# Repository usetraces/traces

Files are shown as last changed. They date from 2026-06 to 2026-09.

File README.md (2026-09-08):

# traces — supercharged ee tools

Open-source tooling for KiCad: semantic component sourcing and schematic review
that runs entirely on **your** machine against **your** API keys. No accounts, no
hosted backend, no billing.

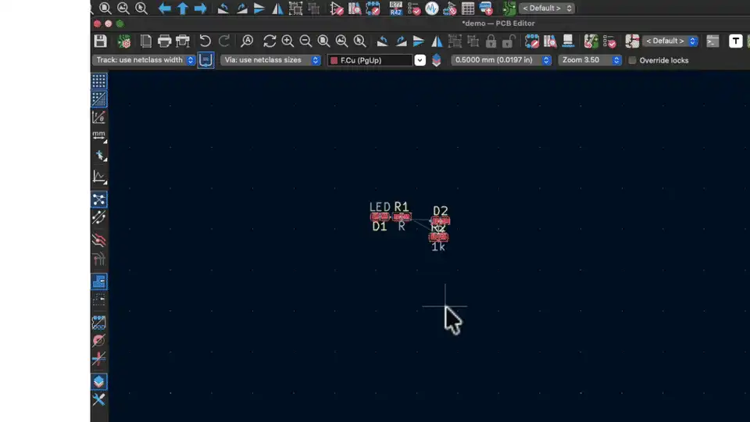
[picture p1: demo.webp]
traces sourcing parts inside KiCad


There are three tools:

1. **mcp** — a local sourcing server you install into your agent
2. **kicad extension** — a KiCad plugin that talks to the local server
3. **semantic rule check (SRC)** — a `/src` skill for Claude Code / Codex

## Setup

One command installs all three tools (server, KiCad plugin, `/src` skill):

```bash
git clone https://github.com/usetraces/traces.git
cd traces
./install.sh           # creates .env, installs deps; pulls a local model if no cloud key
```

`./install.sh` creates `.env` for you. Add keys to it as needed, then re-run if
you like — sourcing works against the local model with **no keys at all**. You
can also install just one piece: `./install.sh mcp | kicad | skill`.

All three tools read keys from the repo-root `.env`:

| Key | Needed for |
|---|---|
| `OPENROUTER_API_KEY` | cloud LLM for sourcing (optional — blank = fully local) |
| `MOUSER_API_KEY` | Mouser sourcing |
| `DIGIKEY_CLIENT_ID` / `DIGIKEY_CLIENT_SECRET` | Digi-Key sourcing |
| _(none)_ | JLCPCB / LCSC sourcing works with no key |

Prerequisites: `./install.sh` auto-installs [uv](https://docs.astral.sh/uv/) and
(for local mode) Ollama. You need Node.js 20+ and KiCad already present.

---

## 1. mcp

A local server that turns natural language ("low-Rds N-MOSFET in SOT-23",
"100nF 0402 X7R") into ranked, in-stock parts across JLCPCB/LCSC, Digi-Key, and
Mouser. The OpenRouter-backed Node agents interpret each request like an
engineer, query the supplier APIs, and the results are merged and ranked
in-stock-first, then by footprint match and price.

```bash
cd mcp
./install.sh        # uv sync + npm install
```

**Run it as a local HTTP server** (what the KiCad extension connects to):

```bash
uv run traces-serve   # serves http://127.0.0.1:8000
```

**Or install the stdio MCP into your agent.** For Claude Code:

```bash
claude mcp add traces -- uv run --directory /path/to/traces/mcp traces-mcp
```

Tools exposed to the agent:

- `source_component(query, footprint?, suppliers?, max_price?, min_qty?, count?)` — ranked in-stock candidates
- `find_datasheet(lcsc)` — datasheet PDF URL for an LCSC C-number
- `netlist_check(xml, check)` — run a semantic rule check over netlist XML

Override the model with `DEFAULT_MODEL` in `.env` (default
`google/gemini-3.1-flash-lite`).

### Running fully local (no OpenRouter key)

If `OPENROUTER_API_KEY` is blank — **or set but broken/unreachable** — traces
automatically falls back to a local [Ollama](https://ollama.com) model. No key,
nothing leaves your machine. The model is `OLLAMA_MODEL` (default `gemma4`).

`./install.sh` sets this up for you: when there's no OpenRouter key it installs
Ollama and pulls `OLLAMA_MODEL`. To do it by hand, or to use a different
tool-capable model (sourcing uses function-calling):

```bash
ollama pull gemma4        # verified; qwen2.5 / llama3.1 also work
# leave OPENROUTER_API_KEY blank in .env (OLLAMA_MODEL=gemma4 is the default)
uv run traces-serve
```

The SRC checks (JSON only) work with any chat model; sourcing needs tool
support. Local runs are slower (tens of seconds per sourcing call) but produce
the same ranked, in-stock results.

### Eval

Smoke-test the pipeline against whichever provider is active:

```bash
uv run traces-eval            # sourcing (all suppliers) + SRC checks
uv run traces-eval --src-only # netlist checks only (no tool-calling needed)
```

Verified end-to-end against local `gemma4` via Ollama — both the SRC checks and
JLCPCB/Digi-Key/Mouser sourcing pass with no OpenRouter key.

### Benchmark

Rank the local model against a set of OpenRouter models on accuracy, speed, and
price. Each model runs the JLCPCB sourcing agent (no supplier key needed) over a
small fixed case set, several trials each:

```bash
uv run traces-bench               # local gemma4 + 5 OpenRouter models, 3 trials
uv run traces-bench --trials 1    # quick pass
uv run traces-bench --no-local    # OpenRouter models only
```

Latest run — 6 models × 3 cases × 3 trials = 54 sourcing calls (JLCPCB):

| Model | Accuracy | Median speed | Avg $/run | Fails |
|---|---|---|---|---|
| `google/gemini-3.1-flash-lite` (shipped default) | 100% | 5.6s | $0.00059 | 0/9 |
| `anthropic/claude-haiku-4.5` | 100% | 7.4s | $0.00394 | 0/9 |
| `qwen/qwen3-235b-a22b-2507` | 100% | 8.0s | $0.00018 | 0/9 |
| `openai/gpt-5-mini` | 100% | 20.9s | $0.00240 | 0/9 |
| `ollama/gemma4` (local) | 100% | 44.7s | $0.00000 | 0/9 |
| `google/gemini-3.5-flash` | 44% | 18.8s | $0.00796 | 0/9 |

Takeaways: the shipped default (`gemini-3.1-flash-lite`) is both the fastest and
the most accurate cloud option; `qwen3-235b` is nearly as good for ~3× less; the
local `gemma4` matches on accuracy at $0 but is ~8× slower. Accuracy here is a
keyword + footprint match proxy, not a guarantee of the optimal part — edit the
model list, cases, and trial count at the top of `mcp/src/traces_mcp/bench.py`.

---

## 2. kicad extension

For the KiCad Plugin and Content Manager package, see the
[installation guide](kicad-extension/README.md). Release maintainers can follow
the [PCM submission guide](kicad-extension/SUBMISSION.md).

A KiCad 10 PCB-editor plugin that reconciles schematic metadata, sources parts
into schematic properties, fetches datasheets, pulls KiCad symbols/footprints
from LCSC, and runs SRC — all against the local server above.

```bash
cd kicad-extension
./install.sh        # copies the plugin into your KiCad plugins dir
```

Then:

1. Start the server: `(cd ../mcp && uv run traces-serve)`
2. Restart KiCad so it loads the plugin.
3. Open a saved PCB → **Tools → External Plugins → traces**.

The plugin points at `http://127.0.0.1:8000`; it does not require sign-in.

---

## 3. semantic rule check (SRC)

A skill for Claude Code / Codex that reviews a local KiCad project for
**semantic** net problems ERC can't catch — net-label typos, inconsistent bus
naming, orphan (single-pin) nets, and near-duplicate net names. The agent does
the reasoning directly, so no server or key is needed.

Install the skill (Claude Code example):

```bash
mkdir -p ~/.claude/skills/src
cp src/SKILL.md ~/.claude/skills/src/
```

Then, from a directory containing a KiCad project:

```
/src
```

See [`src/SKILL.md`](src/SKILL.md) for what each check flags.

---

## Architecture

```
traces/
├── mcp/              # local sourcing server (FastMCP + FastAPI + Node agents)
│   └── src/traces_mcp/
│       ├── mcp_server.py   # stdio MCP  (traces-mcp)
│       ├── app.py          # local HTTP (traces-serve) for the KiCad extension
│       ├── semantic.py     # cross-supplier ranking
│       ├── suppliers/      # JLCPCB / Digi-Key / Mouser clients + sourcing
│       ├── netlist.py      # SRC checks (OpenRouter or local Ollama)
│       ├── library.py      # LCSC symbol/footprint via easyeda2kicad
│       └── agents/*.mjs    # sourcing agents (Node, OpenAI-compatible)
├── kicad-extension/  # KiCad plugin (traces.py)
└── src/              # the /src SRC skill (SKILL.md)
```

The KiCad extension speaks the same `/jobs/*` submit-and-poll contract the old
hosted backend used, so the local server is a drop-in: requests are computed
inline with an in-memory job store — no Redis, no auth, no billing.

## What changed from the hosted version

This repo is the open-source extraction of the original hosted product. Removed:
Supabase auth, Stripe billing, the marketing site / dashboard / stats pages, the
Redis + ARQ job queue, and all account/sign-in flows. The sourcing engine, the
KiCad plugin, and the SRC checks are preserved and rewired to run locally.

## License

MIT — see [LICENSE](LICENSE).

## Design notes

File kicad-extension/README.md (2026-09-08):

# traces for KiCad

Component sourcing, schematic properties, datasheets, library imports, and
semantic netlist checks, launched from the KiCad PCB Editor.

The first Plugin and Content Manager (PCM) package targets **KiCad 10 on macOS**
and is a testing release. The local server is installed separately.

## Install the local server

Install Node.js 20+ and Git, then run:

```sh
git clone https://github.com/usetraces/traces.git
cd traces
git checkout kicad-v2.0.0
./install.sh mcp
```

The installer sets up uv and Python dependencies (Python 3.11+). Configure the
clone's `.env` with your API keys. With no OpenRouter key, the installer attempts
to install Ollama and download the default model. Model downloads can be large.
See the repository README for provider settings and manual Ollama setup.

Run the server in a terminal and leave it running:

```sh
cd mcp
uv run traces-serve
```

The plugin connects to `http://127.0.0.1:8000`. PCM installs only the plugin;
it does not run the backend installer. Automatic server discovery is a convenience
for existing checkouts, not required when the server is already running.

## Install the plugin

1. Download `traces-kicad-2.0.0.zip` from the GitHub release.
2. In KiCad's project manager, open **Plugin and Content Manager**, select
   **Install from File**, choose the ZIP, and apply pending changes if prompted.
3. Restart the PCB Editor. Open a saved PCB belonging to your project.
4. Choose **Tools → External Plugins → traces** (or its toolbar button).

Once accepted into the official repository, traces will also be installable by
name in PCM. Until then, use the release ZIP.

If you previously ran `./install.sh kicad`, move the old `traces.py` and
`traces.png` out of `~/Documents/KiCad/10.0/scripting/plugins/` before restarting
KiCad to avoid duplicate plugin registrations. Keep a backup outside that folder.
Do not run the manual plugin installer on top of a PCM installation.

## Use and updates

The plugin edits schematic files on disk. Save and close the schematic editor
before applying edits, then reopen it to load the changes. Start with a copy of
your project. A running server is required for sourcing and semantic checks.

Local Ollama inference keeps model processing local; component sourcing and
library downloads still contact external suppliers. OpenRouter mode sends model
requests, including the netlist when running semantic checks, to that service.
Digi-Key and Mouser features may require your own supplier credentials.

Install subsequent plugin releases through PCM. Update the separate server to
the corresponding release as described in its release notes. Report problems at
https://github.com/usetraces/traces/issues with your KiCad version and OS, without
including API keys or private design files.

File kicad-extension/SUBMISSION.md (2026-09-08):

# KiCad PCM release and submission

Package: `com.github.usetraces.traces`

First release: `2.0.0` / Git tag `kicad-v2.0.0`

Target: KiCad 10.0, macOS, SWIG runtime, testing status

## Build

From the repository root:

```sh
python3 scripts/build_pcm.py
```

This creates:

- `dist/pcm/traces-kicad-2.0.0.zip` — plugin archive with a package entry point,
  source, icon, MIT license, setup guide, and archive metadata.
- `dist/pcm/submission/packages/com.github.usetraces.traces/metadata.json` —
  GitLab metadata with the final ZIP hash, URL, compressed size, and extracted size.

The ZIP is built from an explicit file list; it excludes `.env`, design files,
Python caches, and the server's dependencies. Builds with the same inputs and
Python/zlib toolchain produce identical bytes. Only the GitLab metadata has
`download_*` fields. `INSTALLED_VERSION` remains `0.0.0` so the old PyPI updater
does not run in PCM installations.

Optional schema validation:

```sh
curl -fL https://go.kicad.org/pcm/schemas/v2 -o /tmp/traces-pcm-v2.schema.json
uv run --no-project --with jsonschema python scripts/build_pcm.py \
  --schema /tmp/traces-pcm-v2.schema.json
```

## Verify and publish

1. Install the ZIP using PCM's **Install from File** and confirm the installed
   version. Avoid loading a duplicate manually installed copy.
2. Follow `README.md` in this directory to start the server and open the plugin
   from a saved PCB. Use a disposable project copy for write operations.
3. Commit the packaging files and documentation. Create the release tag on that
   commit; the source at the tag must match the ZIP's source.
4. Upload the ZIP to a public GitHub release named `traces for KiCad 2.0.0`, with
   tag `kicad-v2.0.0`. Mark the release as a prerelease while PCM status is testing.
5. Download the public release asset and check its SHA-256 against the generated
   submission metadata. Do not change the archive after this check.

## Submit to GitLab

1. Sign in with `glab auth login --hostname gitlab.com`.
2. Fork `https://gitlab.com/kicad/addons/metadata` and create a branch such as
   `add-traces` from its current `main`.
3. Copy the generated `packages/com.github.usetraces.traces/metadata.json` into
   the fork. Commit and push that branch.
4. Check the fork's validation pipeline. Its build job produces a temporary PCM
   repository URL; add that repository in KiCad and test installation.
5. Open a merge request targeting `kicad/addons/metadata:main` with the package
   purpose, release link, backend requirement, and exact validation performed.
   Do not claim supplier-policy approval or tests that have not happened.

Updates use additional merge requests adding release entries to the upstream
metadata. Keep prior entries in the upstream file; the builder emits only the
current version and must not replace upstream release history on later updates.

Official instructions: https://dev-docs.kicad.org/en/addons/

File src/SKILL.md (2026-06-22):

---
name: src
description: Semantic Rule Check (SRC) for KiCad projects — reviews a local KiCad schematic/netlist for net-label typos, naming inconsistencies, orphan (single-pin) nets, and near-duplicate net names. Use when the user runs /src or asks to semantically review a KiCad schematic in the working directory.
---

# SRC — Semantic Rule Check for KiCad

SRC reviews the KiCad project in the current working directory for **semantic**
net problems that KiCad's own ERC cannot catch — the kind of mistakes that pass
electrical rules but are still bugs (a misspelled signal name, an inconsistent
bus, a wire that connects to only one pin). You (the agent) do the reasoning
directly; no server or API key is required.

## When to run

Trigger on `/src`, or when the user asks to "run SRC", "semantically check this
schematic", or "review the netlist".

## Procedure

### 1. Locate the design and produce a netlist

Find the schematic(s):

```bash
find . -name '*.kicad_sch' -not -path '*/backups/*'
```

Prefer a real netlist over raw `.kicad_sch` parsing. If `kicad-cli` is
available, export one (it expands hierarchy and resolves nets):

```bash
kicad-cli sch export netlist --format kicadxml -o /tmp/src-netlist.xml <root>.kicad_sch
```

If `kicad-cli` is not installed, fall back to reading the `.kicad_sch` files
directly and reasoning over the `(label ...)`, `(global_label ...)`, and wire
connectivity. Tell the user which path you took.

Collect the set of **net names** and, for each net, **how many pins/nodes** it
connects to.

### 2. Run the four checks

Apply each of these over the net list. Only report genuine issues; an empty
result for a check is a good outcome.

**a. Typos** — net names that are likely misspellings/transpositions of standard
signal names (TDX→TXD, SWIDO→SWDIO, CAHN→CANH, MOSIO→MOSI). Do **not** flag power
rails (GND, AGND, +3V3, +5V, VBUS, VCC, VDD, VBAT) or conventional abbreviations
(CLK, RST, EN, CS). Severity `error` for clear transpositions, `warning`
otherwise.

**b. Naming consistency** — groups of related nets using mixed conventions:
mixed separators (`CAN_H` + `CANL`), mixed prefix styles (`SPI_MOSI` + `SPIMISO`),
mixed casing (`usbDP` + `USB_DM`), mixed suffixes (`I2C_SCL` + `I2CSDA`). Do not
flag intentional complementary pairs (`CLK`/`CLK_N`, `DATA`/`DATA_B`). Severity
`warning`.

**c. Orphan nets** — any net connecting to exactly **one** pin (a single `<node>`
in the XML). These are almost always a dangling wire or a misnamed net. Do not
flag `PWR_FLAG`/`PWRFLAG` nets or KiCad auto-named nets (`Net-(...`). Severity
`error` for clear dangling connections, `warning` for plausible testpoints/stubs.
Include the component + pin in the message.

**d. Near-duplicates** — pairs of net names within edit distance 1–2 that look
like an accidental naming split (`VIN_GOOD`/`VIN_GOD`, `RESET`/`RESSET`,
`+3V3`/`+3V3A`). Do not flag intentional complementary pairs or genuinely
distinct rails (`+3V3` vs `+5V`). Severity `warning`. Format the location as
`NET_A / NET_B`.

### 3. Report

Print a grouped summary. For each issue: severity, the net name(s), and a
one-line explanation. End with a count, e.g. `SRC: 2 errors, 3 warnings`. If
everything is clean, say so explicitly.

```
SRC results for <project>
  [error]   typo          SWIDO        likely "SWDIO" (SWD I/O)
  [warning] consistency   CAN_H, CANL  mix _ separator within the CAN bus
  [error]   orphan        VBUS_SENSE   connects only to U3 pin 14
  ...
SRC: 2 errors, 1 warning
```

## Notes

- This is a read-only review. Do not modify the schematic unless the user asks.
- These checks mirror the semantic checks built into the traces KiCad extension,
  so results should be consistent between `/src` and the plugin's SRC panel.

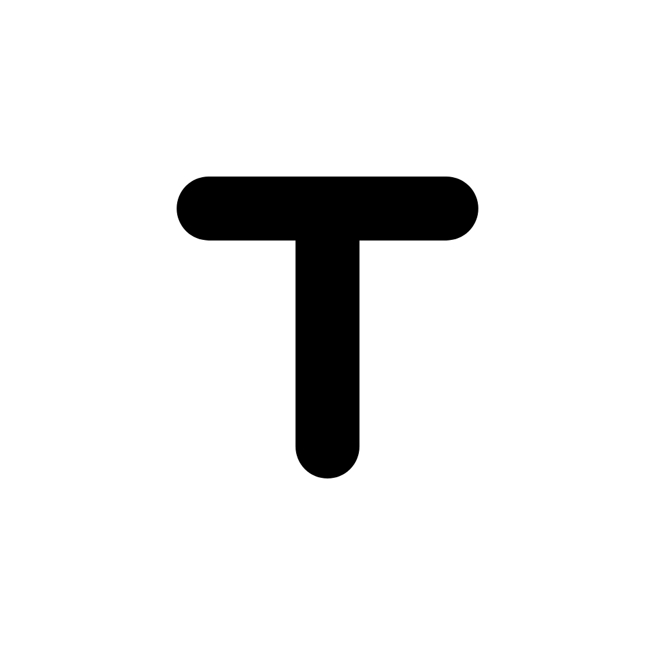
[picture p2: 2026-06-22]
kicad-extension/traces.png

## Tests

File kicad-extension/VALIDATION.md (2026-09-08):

# Initial PCM package validation

Validated on macOS with KiCad 10.0 GUI and KiCad 10.0.1 Python bindings.

- Archive metadata and submission metadata pass the official PCM v2 JSON schema.
- ZIP integrity passes, and rebuilding the same inputs produces the same SHA-256.
- Packaged Python files compile. The packaged schematic parser reads the demo.
- KiCad PCM's **Install from File** installs the archive and lists traces under
  Installed.
- Opening traces from **Tools → External Plugins** in the PCB Editor displays
  its component dialog on a disposable copy of the committed demo project.
- KiCad's scripting console confirms the loaded module lives under
  `10.0/3rdparty/plugins/com_github_usetraces_traces/`.
- The separate local server responds to `/health` with `status: online`.

This is a package installation and launch smoke check. Supplier searches, model
inference, write operations, and a fresh backend dependency installation have
not been re-tested for this packaging change. The GitLab fork pipeline and its
temporary PCM repository must be checked during submission.

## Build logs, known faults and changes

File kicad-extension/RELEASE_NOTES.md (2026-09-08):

First KiCad Plugin and Content Manager package for traces, targeting KiCad 10 on macOS.

This testing release provides component sourcing, schematic metadata editing,
datasheet lookup, symbol/footprint imports, and semantic netlist checks.

Download `traces-kicad-2.0.0.zip` and install it through KiCad's Plugin and Content
Manager using **Install from File**.

**The local backend is installed separately.** It requires Python 3.11+, uv,
Node.js 20+, and either local Ollama or an OpenRouter API key. Some supplier
features require supplier API keys. See the
[installation guide](https://github.com/usetraces/traces/blob/kicad-v2.0.0/kicad-extension/README.md).

This release is prepared for submission to KiCad's official addon repository;
publication here does not mean the package has been accepted there.

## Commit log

2026-06-22 open-source traces
2026-06-25 kicad: auto-start local server on open, drop model footer label
    The plugin now starts `uv run traces-serve` itself if /health isn't
    answering when the dialog opens (detached, clean env, polls up to 20s).
    install.sh records the mcp dir in a `traces_server_path` sidecar so the
    installed plugin can find it. Also removes the "Model:" footer label and
    its /model fetch.
2026-06-25 mcp: add multi-model sourcing benchmark (traces-bench)
    Runs the JLCPCB agent against the local model + 5 OpenRouter models,
    N trials each, and prints a terminal report ranking by accuracy, speed,
    and price (from token usage * per-model rates).
2026-06-25 bench: fix string-candidate crash, fairer scoring, swap in flash-lite
    - Coerce bare part-number strings to {part_number: ...} instead of
    crashing on cands[0].get().
    - Accuracy `must` checks now use equivalence groups (100nF==0.1µF,
    10k==10000, mosfet==n-ch) so a correct part isn't failed on formatting.
    - Replace llama-3.3-70b with google/gemini-3.1-flash-lite (the model the
    extension ships) in the default lineup.
2026-06-25 readme: add benchmark section with latest traces-bench results
2026-06-25 demo: add example KiCad project; ignore local/generated artifacts
    Adds a minimal demo project (pro/sch/pcb) to try the tools against.
    Gitignores KiCad local state (.kicad_prl), lock files, autosave,
    *-backups/, .history/, and the tool-generated demo/datasheets/.
    [demo.kicad_pcb, demo.kicad_sch]
2026-09-08 Package traces for KiCad Plugin and Content Manager
